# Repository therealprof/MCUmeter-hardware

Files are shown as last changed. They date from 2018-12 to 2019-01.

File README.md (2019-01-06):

# The MCUmeter

The MCUmeter started as a gift for a "secret santa" round at my favourite electronics club, the [Boldport Club](https://www.boldport.com/). It was something I always wanted to do because it's useful, simple to build and can offers a nice learning experience for people who want to do microcontroller based hardware themselves.

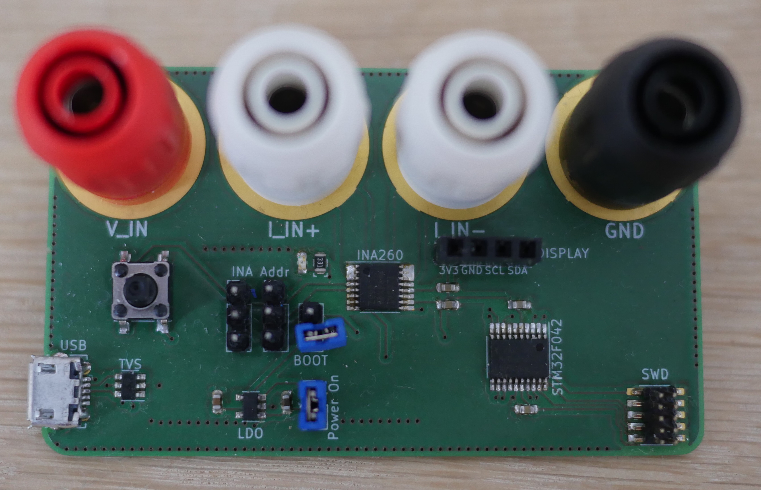
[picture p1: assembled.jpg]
Assembled MCUmeter with shrouded connectors


## What is it?

In a nutshell it’s a high performance voltage/current/power monitor which will render it’s voltags/current/power readings supplied by a Texas Instruments INA260 via a STM32F042 microcontroller onto a small OLED display.

It consists of two main ingredients:

-   Custom made hardware, which is what this repository is all about
-   Software which is written in Rust and can be found [here](https://github.com/therealprof/MCUmeter-software) or directly on [crates.io](https://crates.io/crates/mcumeter)

The hardware design was done in KiCad and this repository contains both the KiCad 5 design files as well as the Gerber files which can be sent directly to a fab house to build the project, like the one I used for the prototypes. If you'd like you can order them directly from Aisler using [this link](https://aisler.net/p/ARZKLTZG).

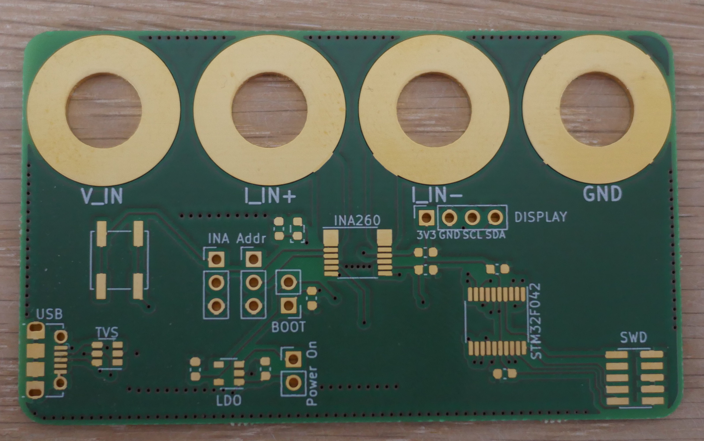
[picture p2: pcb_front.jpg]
front view
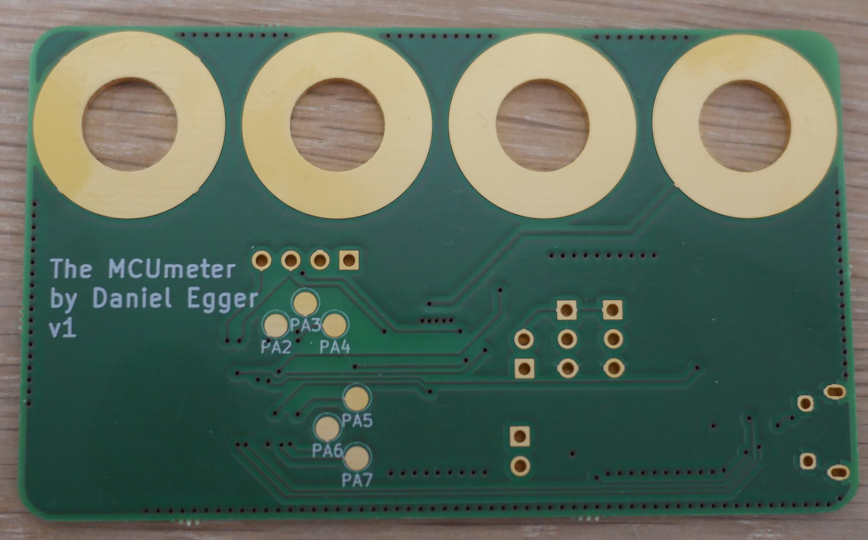
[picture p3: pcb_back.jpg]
back view
This is what the boards look like:  and 

## Hardware connections

The [INA260](http://www.ti.com/lit/ds/symlink/ina260.pdf) allows sensing voltages (DC and positive values only!) up to 36V and high-side as well as low-side currenty (polarity not relevant). It can also do the power calculations, although at reduced precision.

The connections (from left to right) are

-   V_IN:  Positive voltage to be measured. Important! This power meter does not like negative voltages so watch the polarity!
-   I\_IN+/I\_IN-: High-side (i.e. connected between the power supply and DUT) or Low-side (i.e. connected between ground and the DUT) current measuring. Polarity irrelevant.
-   GND: Ground of voltage measurement, common with the rest of the circuit

It also provides a 4-pin header to connect a SSD1306 OLED display with I2C interface using the following pinout:

-   VCC
-   Ground
-   SCL
-   SDA

The connectors can be either soldered onto the board or screwed on, good results have been achieved with e.g. MC/Stäubli XUB-G

## Can I reuse the hardware for my own ideas?

Absolutely, everything is licensed under the BSD license so please go ahead and use it however you'd like.

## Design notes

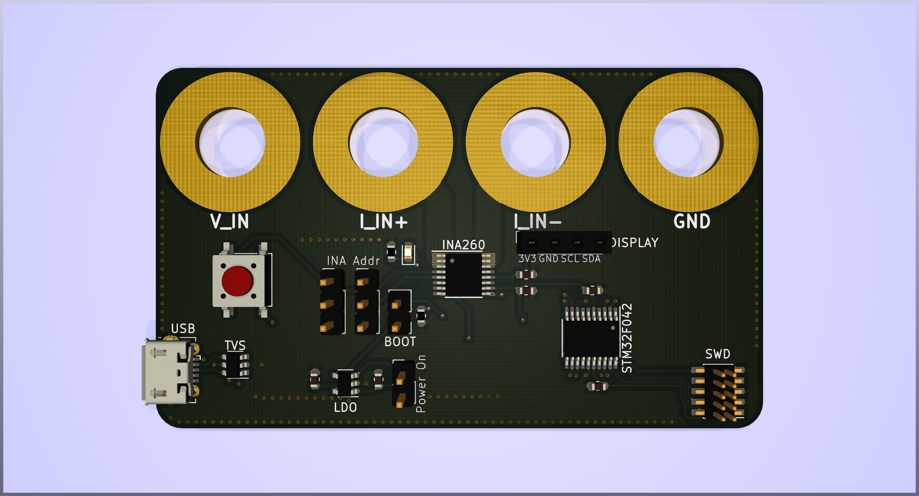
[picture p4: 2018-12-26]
v1/MCUmeter.png

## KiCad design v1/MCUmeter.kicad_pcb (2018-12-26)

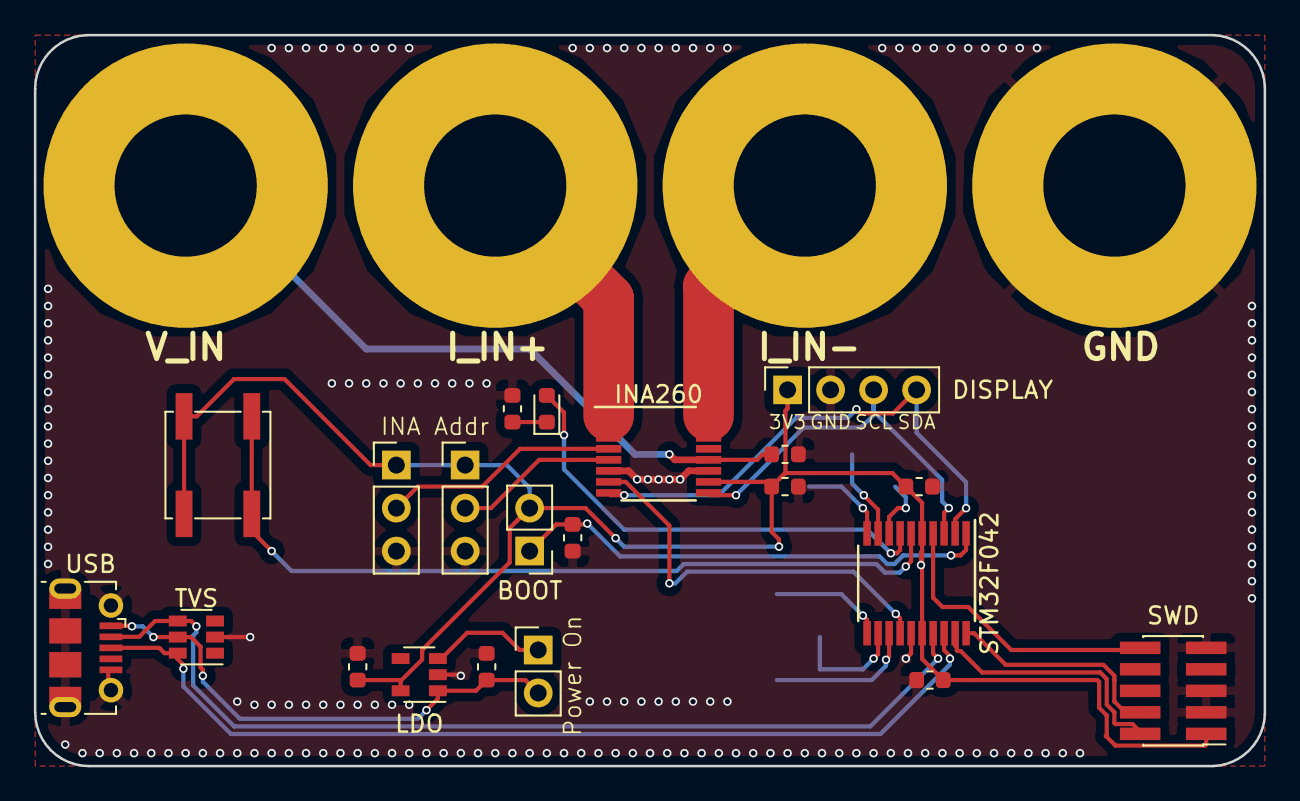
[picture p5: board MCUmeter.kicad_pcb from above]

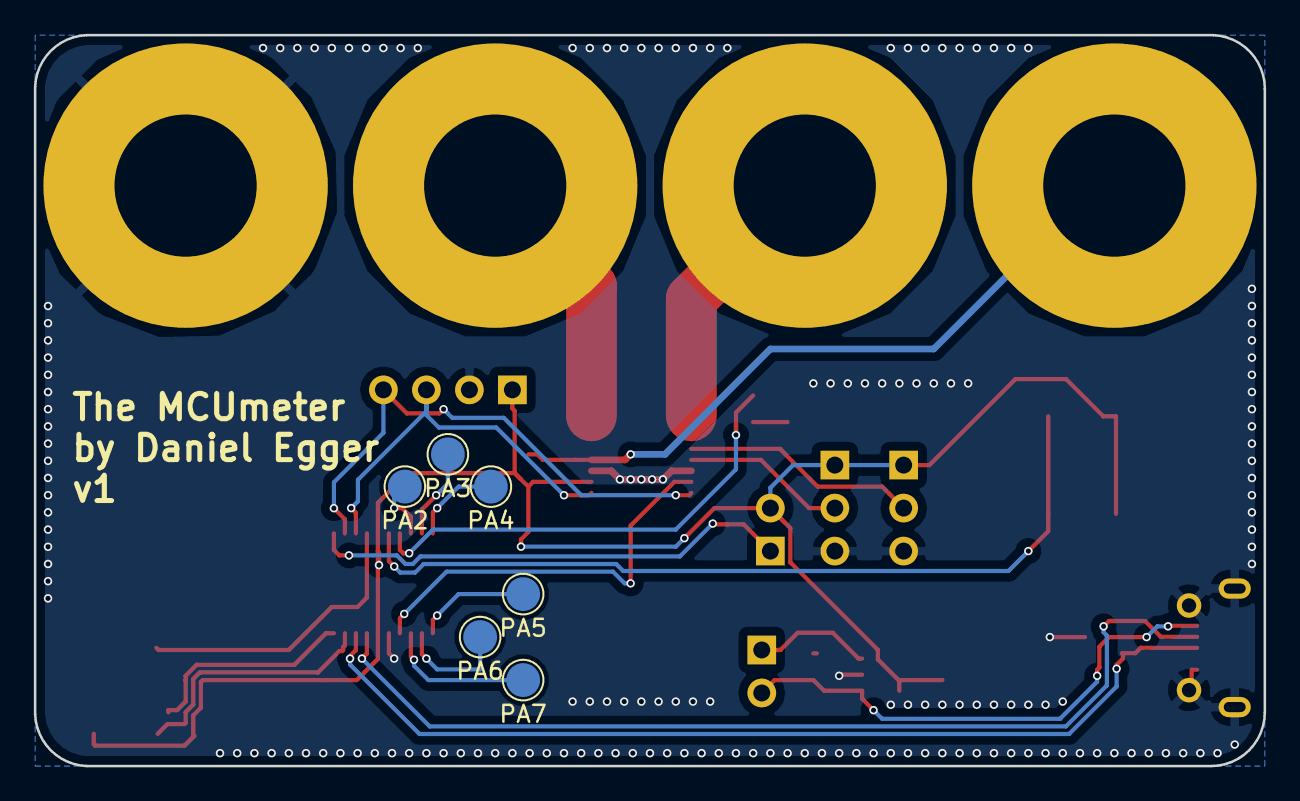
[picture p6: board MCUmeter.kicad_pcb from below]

Board: 2 copper layers, 72.6 x 43.2 mm, 31 parts (6 on the bottom side), 27 nets.

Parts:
BOOT: Conn_01x02; PinHeader_1x02_P2.54mm_Vertical
C1, C4: 1µ; C_0603_1608Metric
C2, C3, C5, C6: 100n; C_0603_1608Metric
D1: LED; LED_0603_1608Metric
DISPLAY: Conn_01x04_Female; PinSocket_1x04_P2.54mm_Vertical
H1, H2, H3, H4: MountingHole_Pad; MountingHole_8.4mm_M8_Pad
INA260: INA260; TSSOP-16_4.4x5mm_P0.65mm
J5, J6: Conn_01x03; PinHeader_1x03_P2.54mm_Vertical
J9: Conn_01x02; PinHeader_1x02_P2.54mm_Vertical
LDO: MIC5504-3.3YM5; SOT-23-5
PA2, PA3, PA4, PA5, PA6, PA7: TestPoint; TestPoint_Pad_D2.0mm
R1: 10k; R_0603_1608Metric
R2: 500R; R_0603_1608Metric
STM32F042: STM32F042F6Px; TSSOP-20_4.4x6.5mm_P0.65mm
SW1: SW_Push; SW_SPST_EVPBF
SWD: Conn_ARM_JTAG_SWD_10; PinHeader_2x05_P1.27mm_Vertical_SMD
TVS: USBLC6-2SC6; SOT-23-6
USB: USB_B_Micro; USB_Micro-B_Molex-105017-0001

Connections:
+3V3: BOOT.2, C2.1, C3.2, C4.1, C6.1, DISPLAY.1, INA260.10, J5.1, J6.1, LDO.5, STM32F042.5, STM32F042.16, SW1.2, SWD.1
/ALERT: INA260.7, STM32F042.14
/HIGH: C5.1, H1.1, INA260.12
/IN+: H2.1, INA260.1, INA260.2, INA260.3
/IN-: H3.1, INA260.14, INA260.15, INA260.16
/SCL: DISPLAY.3, INA260.9, STM32F042.3
/SDA: DISPLAY.4, INA260.8, STM32F042.2
/SWDCLK: STM32F042.20, SWD.4
/SWDIO: STM32F042.19, SWD.2
/USB_DM: STM32F042.17, TVS.4, USB.2
/USB_DP: STM32F042.18, TVS.6, USB.3
/VBUS: C1.1, J9.2, LDO.1, TVS.5, USB.1
/~RST: STM32F042.4, SWD.10
GND: C1.2, C2.2, C3.1, C4.2, C5.2, C6.2, DISPLAY.2, H4.1, INA260.6, INA260.11, J5.3, J6.3, LDO.2, R1.2, R2.1, STM32F042.15, SWD.3, SWD.5, SWD.9, TVS.2, USB.5, USB.6
unnamed: D1.1, R2.2
unnamed: D1.2, STM32F042.7
unnamed: BOOT.1, R1.1, STM32F042.1
unnamed: INA260.4, J5.2
unnamed: INA260.5, J6.2
unnamed: J9.1, LDO.3
unnamed: STM32F042.6, SW1.1
unnamed: PA2.1, STM32F042.8
unnamed: PA3.1, STM32F042.9
unnamed: PA4.1, STM32F042.10
unnamed: PA5.1, STM32F042.11
unnamed: PA6.1, STM32F042.12
unnamed: PA7.1, STM32F042.13
